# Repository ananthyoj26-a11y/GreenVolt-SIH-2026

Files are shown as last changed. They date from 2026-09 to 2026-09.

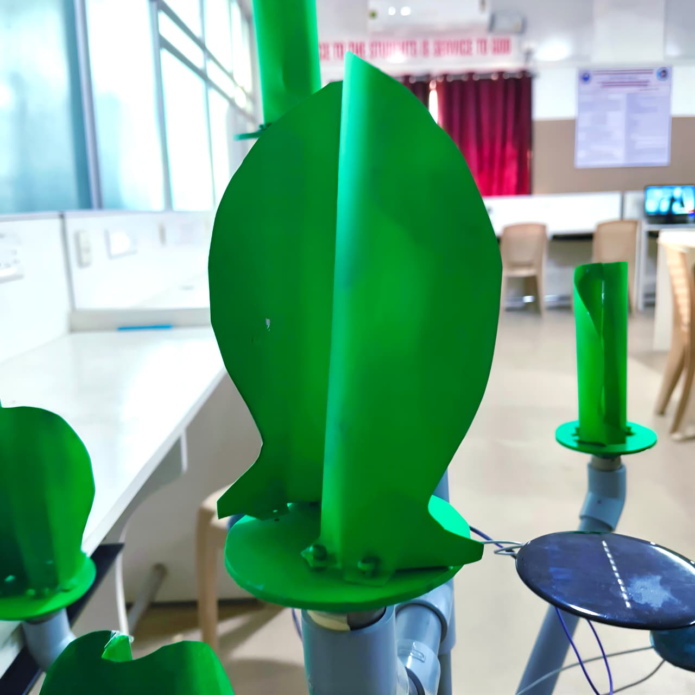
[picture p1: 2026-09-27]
media/prototype_photos/WhatsApp Image 2026-04-01 at 5.27.39 PM.jpeg

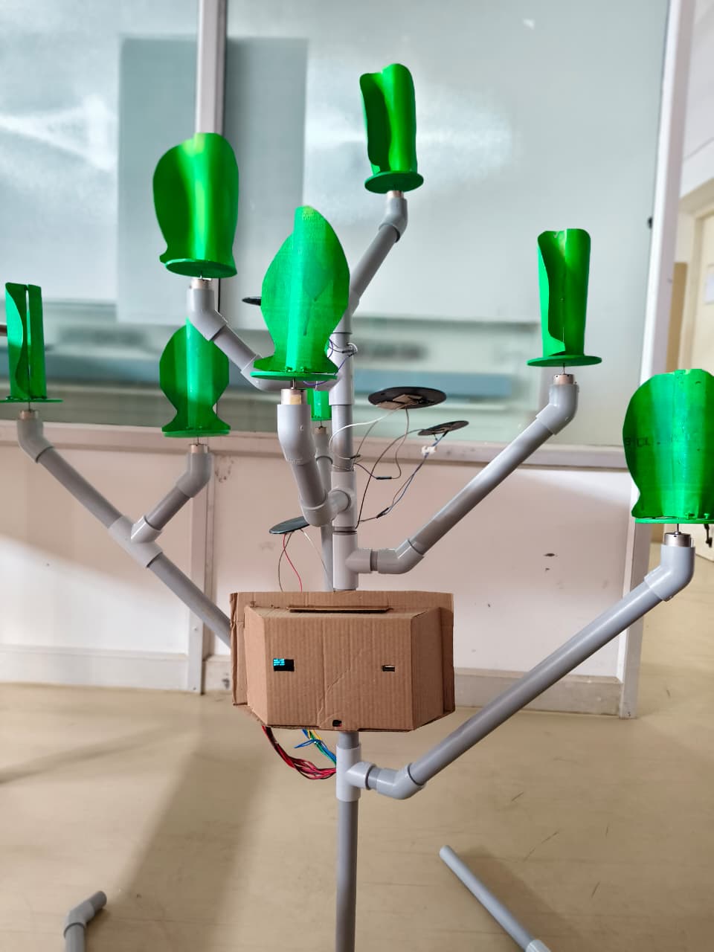
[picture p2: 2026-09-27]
media/prototype_photos/WhatsApp Image 2026-04-01 at 5.27.40 PM.jpeg

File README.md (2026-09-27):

# GREENVOLT — Hybrid Wind-Solar Energy Tree

**Smart India Hackathon 2026 | Problem Statement 26217**  
**Theme:** Renewable / Sustainable Energy  
**Category:** Hardware  
**Project:** Dual Mode Tree — Hybrid Solar–Wind Energy Generation and Monitoring System

## 1. Project Overview

GreenVolt, also referred to as the **Dual Mode Tree**, is a compact, tree-inspired hybrid renewable-energy concept that combines solar photovoltaic generation with an AeroLeaf-inspired vertical-axis wind turbine.

The system is intended to demonstrate how two naturally variable renewable sources can be integrated into a common power-management and monitoring architecture.

The project focuses on:

- Hybrid solar + wind energy harvesting
- AeroLeaf / Savonius-inspired vertical-axis wind capture
- Modular multi-generator wind architecture
- Source-specific power conditioning and MPPT
- Common DC-bus integration
- Battery energy storage
- ESP32-based monitoring
- Electrical protection and wind braking
- Modular fabrication and serviceability
- Experimental validation of actual electrical output

## 2. Problem

Solar generation is unavailable at night and decreases during cloudy conditions. Urban wind can also be low, gusty and directionally variable.

GreenVolt addresses these system-level challenges by combining solar and wind generation in one compact structure and providing monitoring, protection and modular maintenance features.

## 3. Proposed System

### Renewable sources

**Solar subsystem**
- 4 × 20 W photovoltaic panels
- Installed PV capacity: 80 W
- Modular branch-mounted arrangement

**Wind subsystem**
- AeroLeaf / Savonius-inspired VAWT
- Up to 8 low-KV BLDC/gimbal generator units
- Individual three-phase rectification
- Experimental optimization using wind speed, RPM, torque, voltage, current and power

### Monitoring

ESP32-based monitoring is intended to measure:
- Voltage
- Current
- Power
- Rotor RPM
- Battery status
- Wind speed
- Irradiance / environmental parameters where sensors are available

The planned communication architecture uses Wi-Fi with MQTT and a dashboard such as ThingsBoard, Blynk, or Node-RED.

## 4. Electrical Architecture — IMPORTANT STATUS NOTE

The current project documentation contains **legacy 24 V references**, while the latest GreenVolt presentation direction requested by the team uses a **48 V shared DC bus**.

Therefore, this repository deliberately separates:
- **Source/document-derived specifications**
- **Latest proposed architecture**
- **Measured/validated results**

Before final submission, all hardware, battery, charge-controller, protection, converter, wiring and load ratings must be verified for the selected bus voltage.

See:
`docs/ARCHITECTURE_STATUS.md`

## 5. Evidence Policy

This repository distinguishes:

- **MEASURED** — directly obtained from physical instrumentation/testing
- **CALCULATED** — obtained from equations/model assumptions
- **SIMULATED** — generated using software models
- **PLANNED** — intended future test/design
- **TARGET** — design objective, not a measured result

No calculated or target value should be presented as measured prototype performance.

## 6. Repository Structure

```text
GreenVolt-SIH-2026/
├── README.md
├── LICENSE_DECISION.md
├── .gitignore
├── docs/
│   ├── PROJECT_OVERVIEW.md
│   ├── ARCHITECTURE_STATUS.md
│   ├── SYSTEM_ARCHITECTURE.md
│   ├── TECHNICAL_APPROACH.md
│   ├── MPPT_AND_CONTROL.md
│   ├── BRAKING_AND_SAFETY.md
│   ├── IOT_MONITORING.md
│   ├── FEASIBILITY_AND_RISKS.md
│   ├── IMPACT_AND_APPLICATIONS.md
│   ├── RESEARCH_AND_PRIOR_ART.md
│   ├── VALIDATION_PLAN.md
│   └── FUTURE_SCOPE.md
├── hardware/
│   ├── BOM.csv
│   ├── COMPONENT_SELECTION.md
│   ├── WIRING_AND_PROTECTION.md
│   └── datasheets/README.md
├── calculations/
│   ├── POWER_CALCULATION_TEMPLATE.md
│   ├── WIND_OUTPUT_TEMPLATE.csv
│   └── SOLAR_OUTPUT_TEMPLATE.csv
├── testing/
│   ├── TEST_PROTOCOL.md
│   ├── RAW_DATA_TEMPLATE.csv
│   └── VALIDATION_STATUS.md
├── software/
│   ├── esp32/README.md
│   ├── mppt/README.md
│   └── dashboard/README.md
├── simulation/
│   └── README.md
├── media/
│   ├── README.md
│   ├── prototype_photos/
│   └── prototype_video/
├── references/
│   └── README.md
└── team/
    └── TEAM.md
```

## 7. Current Design Targets

The uploaded project document specifies:
- Solar capacity: 80 W
- Target budget: approximately ₹50,000
- Prototype budget listed in the document: ₹48,500
- Wind subsystem: up to 8 low-KV BLDC/gimbal motors
- Tree height: approximately 2.5 m
- Target applications: IoT devices, small DC loads, lighting, campuses and public spaces

These are design/document values unless supported by measured evidence.

## 8. Development Philosophy

GreenVolt is being developed as an experimentally validated hardware system. Generator output, rotor performance, conversion losses, battery behavior and overall energy yield must be established through testing rather than inferred from motor nameplate ratings.

## 9. Team

See `team/TEAM.md`.

## 10. Status

**Prototype / Engineering Validation**

The repository is intended to provide transparent technical evidence for judges, reviewers and future development.

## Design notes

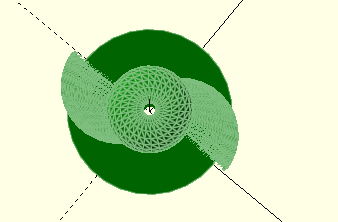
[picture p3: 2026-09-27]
hardware/CAD/AeroLeaf/Screenshot 2026-06-04 141654.png

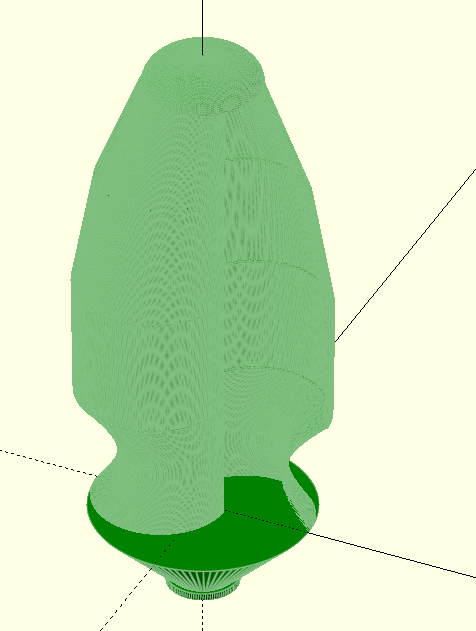
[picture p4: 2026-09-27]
hardware/CAD/AeroLeaf/Screenshot 2026-06-04 105716.png

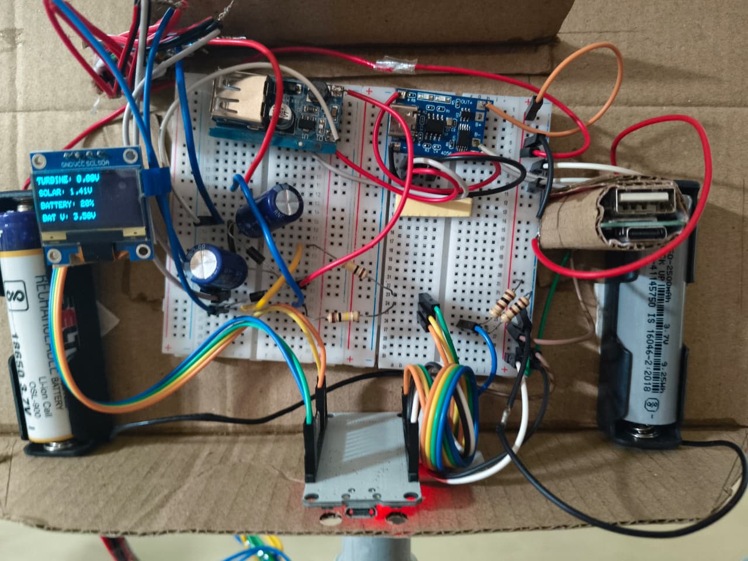
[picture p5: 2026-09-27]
media/prototype_photos/WhatsApp Image 2026-04-01 at 5.28.15 PM.jpeg

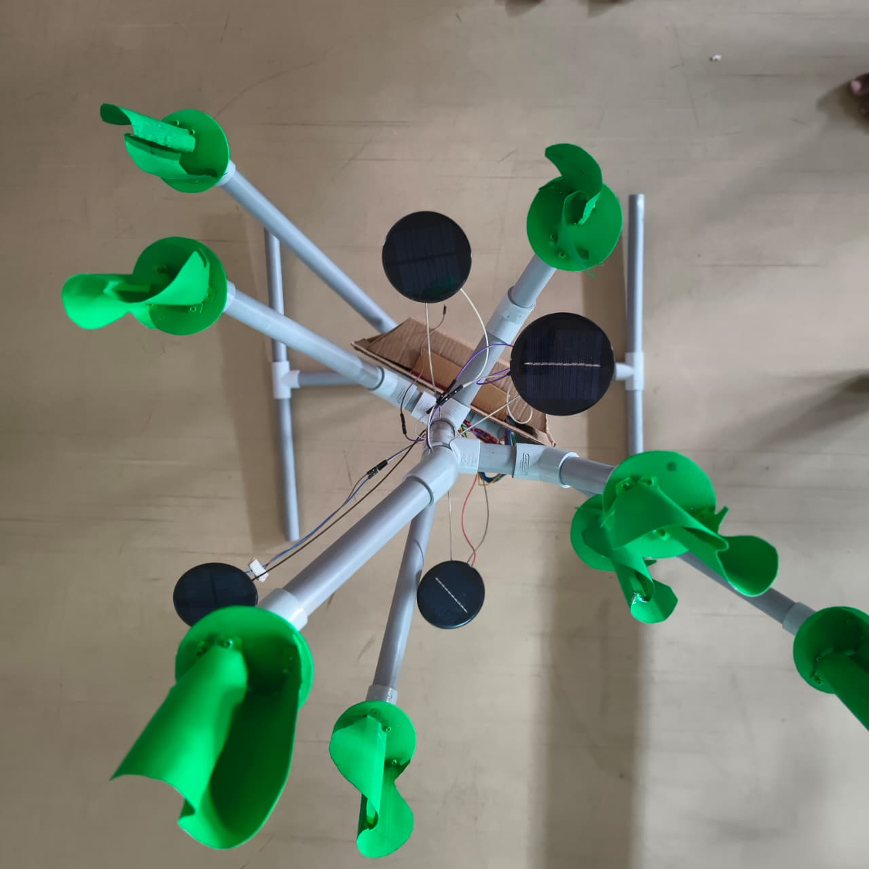
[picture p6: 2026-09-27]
media/prototype_photos/WhatsApp Image 2026-04-01 at 5.27.38 PM.jpeg

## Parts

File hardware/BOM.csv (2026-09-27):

Subsystem | Component | Specification | Qty | Documented Cost INR | Status/Note
Energy Harvesting | Solar PV Panels | 4 x 20 W monocrystalline flexible | 4 | 4800 | Documented design
Energy Harvesting | Wind Generators | Low-KV gimbal BLDC motors | 8 | 8000 | Experimental generator units
Energy Harvesting | AeroLeaf Rotors | Thin aluminium / ACP blades | 8 sets | 2500 | Prototype design
Power | Wind Rectifiers | 3-phase bridge modules | 8 | 800 | Verify exact part rating before procurement
Power | Solar Controller | 24 V nominal 10 A PWM/MPPT in source document | 1 | 1000 | Legacy 24 V item; update if 48 V is final
Storage | Battery Bank | 24 V 20 Ah lead-acid bank in source document | 1 | 4500 | Legacy 24 V item; replace/verify for final architecture
Power | Inverter | 24 V DC to 230 V AC 300–500 W | 1 | 2000 | Optional; legacy 24 V item
Control | ESP32 | ESP32-WROOM-32 | 1 | 500 | Monitoring
Sensors | Power Sensors | INA219 / ACS712 modules | 1 set | 1000 | Verify voltage/current range
Sensors | Speed Sensor | Hall-effect sensor | 2 | 300 | RPM measurement
Structure | Tree Structure | 2.5 m MS/aluminium frame | 1 set | 6000 | Documented design
Mechanical | Mechanical Drive | EN8 shafts/pillow blocks/GT2 belts or couplings | 1 set | 3900 | Documented design
Safety | Electrical Safety | IP65 enclosure | breakers | fuses | E-stop | 1 set | 2200 | Documented design
Wiring | Wiring and Hardware | 14 AWG cables | MC4 | terminals | SS screws | 1 set | 2700 | Documented design
Demo | Finishing and Demo | Coating and 24 V LED load in source document | 1 set | 3000 | Legacy 24 V item
Contingency | Spare Hardware | Diodes/wire/structural hardware | Lump | 1600 | Contingency
TOTAL |  |  |  | 48500 | Source-document total

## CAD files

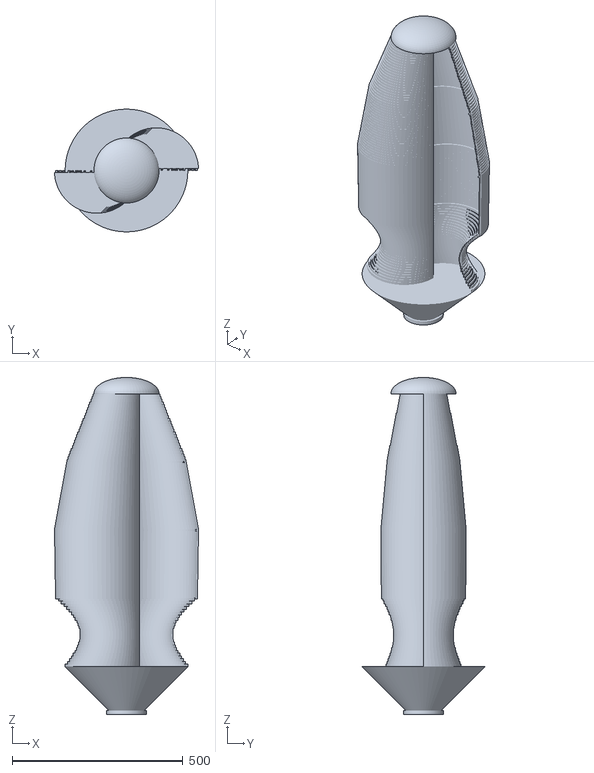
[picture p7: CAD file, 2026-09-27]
hardware/CAD/AeroLeaf/Leaf design.stl
422.4 x 360.0 x 987.7

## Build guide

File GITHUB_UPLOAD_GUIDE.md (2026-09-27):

# GreenVolt — GitHub Upload Guide

## Step 1 — Create the repository

1. Sign in to GitHub.
2. Click **New repository**.
3. Repository name:
   `GreenVolt-SIH-2026`
4. Description:
   `GreenVolt — Hybrid Wind-Solar Energy Tree | Smart India Hackathon 2026 | PS 26217`
5. Select **Public** if this is the judge-facing repository.
6. Do not add another README if this bundle already contains one.
7. Create the repository.

## Step 2 — Prepare the local folder

Extract:
`GreenVolt-SIH-2026-GitHub-Complete-Bundle.zip`

The extracted folder should be named:
`GreenVolt-SIH-2026`

## Step 3 — Add your actual evidence

Before publishing, add:

### Prototype
- actual prototype photos
- full prototype video
- CAD files
- wiring diagram
- circuit diagram
- AeroLeaf dimensions/drawing

### Hardware
- verified BOM
- component datasheets
- battery/BMS specification
- MPPT/controller datasheets
- generator datasheets
- protection-device ratings

### Testing
- raw measurement CSV files
- test setup photos
- multimeter/instrument photos
- solar test results
- wind test results
- hybrid test results
- battery test results

### Software
- ESP32 code
- sensor calibration code
- MPPT implementation
- dashboard code
- MATLAB/Simulink models

### Evidence
Every result should be labeled:
MEASURED / CALCULATED / SIMULATED / TARGET / PLANNED.

## Step 4 — Check secrets

Never upload:
- Wi-Fi passwords
- MQTT passwords
- API keys
- tokens
- cloud credentials
- private keys
- personal confidential files

## Step 5 — Upload through GitHub website

Open the repository.

Click:
**Add file → Upload files**

Drag the complete contents of the extracted `GreenVolt-SIH-2026` folder into the upload area.

For large files, use Git LFS or GitHub Releases rather than putting very large binaries directly into normal Git history.

Enter commit message:
`Initial GreenVolt SIH 2026 technical evidence repository`

Click:
**Commit changes**

## Step 6 — Verify the repository

Open the public repository and check:

- README renders correctly
- all folders open
- Energy_Sheet.xlsx downloads/opens
- PDFs open
- images display
- source code is visible
- no credentials are exposed
- links work

## Step 7 — Add the GitHub link to the SIH PPT

Use the public repository URL in the PPT.

Recommended link text:

**GitHub — Technical Evidence & Prototype Documentation**

## Step 8 — Final judge path

A judge should be able to follow:

README
→ System Architecture
→ Hardware / BOM
→ Prototype Photos
→ Measurements
→ Calculations
→ ESP32 / Software
→ Video
→ Future Scope

without needing permission.

## Step 9 — Final consistency check

Before submission, verify that:
- final bus voltage is consistent everywhere
- battery voltage matches the final architecture
- controller ratings match the bus
- dashboard numbers match measurements
- theoretical results are labeled
- prototype claims have evidence

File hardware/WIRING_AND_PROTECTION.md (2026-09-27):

# Wiring and Protection

## Source branches

Each solar and wind branch should be individually identifiable and isolatable.

## Recommended documentation

Create a wiring diagram showing:
- source positive/negative
- rectifier
- MPPT/controller
- fuse
- isolator
- blocking diode if required
- common bus
- battery
- load
- ESP32 sensing points
- emergency stop

## 48 V architecture requirement

If the final architecture is 48 V, all components must be selected and documented for 48 V operation.

Do not reuse the legacy 24 V battery/controller/inverter specifications without verification.

## Cable sizing

Select cables based on:
- maximum current
- cable length
- allowable voltage drop
- temperature
- insulation rating
- installation environment

## Safety

Use suitable:
- DC-rated fuses/breakers
- isolators
- enclosure
- grounding/earthing
- emergency stop
- mechanical guarding

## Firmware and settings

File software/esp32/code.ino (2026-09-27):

#define BLYNK_TEMPLATE_ID "YOUR_BLYNK_TEMPLATE_ID"
#define BLYNK_TEMPLATE_NAME "YOUR_BLYNK_TEMPLATE_NAME"
#define BLYNK_AUTH_TOKEN "YOUR_BLYNK_AUTH_TOKEN"

#include <WiFi.h>
#include <WiFiClient.h>
#include <BlynkSimpleEsp32.h>
#include <Wire.h>
#include <Adafruit_GFX.h>
#include <Adafruit_SSD1306.h>
#include <HTTPClient.h>

// --- WiFi Credentials ---
char ssid[] = "YOUR_WIFI_SSID";
char pass[] = "YOUR_WIFI_PASSWORD";

// --- Google Sheets Config ---
const char* GOOGLE_SCRIPT_URL = "https://script.google.com/macros/s/YOUR_SCRIPT_ID/exec";

// --- OLED & Pin Config ---
#define OLED_ADDR 0x3C
Adafruit_SSD1306 display(128, 64, &Wire, -1);

#define BATTERY_ADC_PIN 34 
#define BUS_ADC_PIN     35 
#define SOLAR_BUS_PIN   32

// --- Calibration Factors ---
const float BAT_CAL_FACTOR = 3.89/2200; 
const float BUS_CAL_FACTOR = 1.80/2055; 
const float SOLAR_BUS_FACTOR = 1.80/2055;

BlynkTimer timer;
bool blynkConnected = false;

// --- Calculation Functions ---
float readADCVoltage(int adcPin, float calFactor) {
    long raw_value = 0;
    for(int i=0; i<64; i++) { 
        raw_value += analogRead(adcPin); 
        delay(1); 
    }
    return ((float)raw_value / 64.0) * calFactor;
}

float getBatterySOC(float voltage) {
    if (voltage >= 4.20) return 100.0;
    if (voltage >= 4.00) return 90.0;
    if (voltage >= 3.85) return 75.0;
    if (voltage >= 3.70) return 50.0;
    if (voltage >= 3.50) return 20.0;
    if (voltage >= 3.30) return 5.0;
    return 0.0;
}

// --- Google Sheets Logging Function ---
void logToGoogleSheets(float solarV, float windV, float batteryV, const char* mode) {
    if (WiFi.status() == WL_CONNECTED) {
        HTTPClient http;

        String url = String(GOOGLE_SCRIPT_URL);
        url += "?solar=" + String(solarV, 2);
        url += "&wind=" + String(windV, 2);
        url += "&battery=" + String(batteryV, 2);
        url += "&mode=" + String(mode);

        http.begin(url);
        http.GET();
        http.end();
    }
}

// --- Function to Send Data ---
void sendSensorData() {
    float batteryVoltage = readADCVoltage(BATTERY_ADC_PIN, BAT_CAL_FACTOR);
    float busVoltage     = readADCVoltage(BUS_ADC_PIN, BUS_CAL_FACTOR);
    float solarvoltage   = readADCVoltage(SOLAR_BUS_PIN, SOLAR_BUS_FACTOR);
    float socPercent     = getBatterySOC(batteryVoltage);

    // Update Local OLED
    display.clearDisplay();
    display.setTextSize(1);
    display.setTextColor(SSD1306_WHITE);
    
    display.setCursor(0, 0);
    display.print("TURBINE: ");
    display.print(busVoltage, 2);
    display.print("V");

    display.setCursor(0, 16);
    display.print("SOLAR: ");
    display.print(solarvoltage, 2);
    display.print("V");
    
    display.setCursor(0, 32);
    display.print("BATTERY: ");
    display.print(socPercent, 0);
    display.print("%");
    
    display.setCursor(0, 48);
    display.print("BAT V: ");
    display.print(batteryVoltage, 2);
    display.print("V");
    
    display.display();
    
    // Send to Blynk only if connected
    if(blynkConnected) {
        Blynk.virtualWrite(V35, busVoltage);
        Blynk.virtualWrite(V34, batteryVoltage);
        Blynk.virtualWrite(V1, socPercent);
        Blynk.virtualWrite(V32, solarvoltage);
    }
    
    // Send to Google Sheets
    logToGoogleSheets(solarvoltage, busVoltage, batteryVoltage, "HYBRID");
}

// --- Display Energy Tree Logo ---
void showLogo() {
    display.clearDisplay();
    display.fillRect(58, 40, 12, 24, SSD1306_WHITE);
    display.fillCircle(64, 30, 18, SSD1306_WHITE);
    display.fillCircle(50, 35, 12, SSD1306_WHITE);
    display.fillCircle(78, 35, 12, SSD1306_WHITE);
    
    display.setTextSize(2);
    display.setTextColor(SSD1306_WHITE);
    display.setCursor(10, 10);
    display.print("ENERGY");
    display.setCursor(25, 50);
    display.print("TREE");
    display.display();
    delay(2000);
}

// --- WiFi Connection with Timeout ---
bool connectWiFiWithTimeout() {
    display.clearDisplay();
    display.setTextSize(1);
    display.setCursor(0, 20);
    display.print("Connecting WiFi...");
    display.display();
    
    WiFi.begin(ssid, pass);
    unsigned long startTime = millis();
    
    while (WiFi.status() != WL_CONNECTED) {
        if (millis() - startTime > 5000) {
            display.clearDisplay();
            display.setCursor(0, 20);
            display.print("WiFi Timeout!");
            display.setCursor(0, 35);
            display.print("Running Offline");
            display.display();
            delay(1500);
            return false;
        }
        delay(100);
    }
    
    display.clearDisplay();
    display.setCursor(0, 20);
    display.print("WiFi Connected!");
    display.display();
    delay(1000);
    return true;
}

void setup() {
    Serial.begin(115200);
    
    // Initialize OLED
    if(!display.begin(SSD1306_SWITCHCAPVCC, OLED_ADDR)) { 
        Serial.println("OLED init failed!");
        for(;;); 
    }
    
    // Show Logo
    showLogo();
    
    // Try WiFi connection
    if(connectWiFiWithTimeout()) {
        display.clearDisplay();
        display.setCursor(0, 25);
        display.print("Connecting Blynk...");
        display.display();
        
        Blynk.config(BLYNK_AUTH_TOKEN);
        if(Blynk.connect()) {
            blynkConnected = true;
            display.clearDisplay();
            display.setCursor(0, 25);
            display.print("Blynk Connected!");
            display.display();
            delay(1000);
        } else {
            display.clearDisplay();
            display.setCursor(0, 20);
            display.print("Blynk Failed!");
            display.setCursor(0, 35);
            display.print("Running Local");
            display.display();
            delay(1500);
        }
    }
    
    timer.setInterval(2000L, sendSensorData);
}

void loop() {
    if(blynkConnected) {
        Blynk.run();
    }
    timer.run();
}
*newly added spread sheet data collection*

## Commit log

2026-09-27 Add complete GreenVolt SIH 2026 evidence repository
    [BOM.csv, Energy_Sheet.xlsx, RAW_DATA_TEMPLATE.csv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]
2026-09-27 Create README.md
    # AeroLeaf CAD Design
    OpenSCAD source and supporting design files for the AeroLeaf wind rotor/blade geometry used in the GreenVolt hybrid wind subsystem.
    ## Evidence Status
    CAD/design evidence — not a measured aerodynamic performance result.
